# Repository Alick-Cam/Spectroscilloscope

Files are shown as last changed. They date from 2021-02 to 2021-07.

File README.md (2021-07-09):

# FYP-Repo
Software for Final Year Project 2020

Design and develop the necessary hardware and software systems needed to implement an
Oscilloscope and a Spectrum Analyser on a tablet/smartphone running the Android operating
system. To safeguard the handheld device it should communication via the Bluetooth with an
interfacing device that connects to the device under test.
Specifications (oscilloscope and spectrum analyser):
- Frequency: 0Hz – 20kHz.
- Voltage (AC and DC): 0V - 250V
- The device should be designed to use standard oscilloscope probes

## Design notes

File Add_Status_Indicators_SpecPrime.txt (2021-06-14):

<?xml version="1.0" encoding="utf-8"?>
<androidx.constraintlayout.widget.ConstraintLayout xmlns:android="http://schemas.android.com/apk/res/android"
    xmlns:app="http://schemas.android.com/apk/res-auto"
    xmlns:tools="http://schemas.android.com/tools"
    android:layout_width="match_parent"
    android:layout_height="match_parent"
    android:layout_gravity="bottom"
    tools:context=".MainActivity">

    <com.github.mikephil.charting.charts.LineChart
        android:id="@+id/line_chart"
        android:layout_width="match_parent"
        android:layout_height="496sp"
        app:layout_constraintBottom_toBottomOf="parent"
        app:layout_constraintEnd_toEndOf="parent"
        app:layout_constraintStart_toStartOf="parent"
        app:layout_constraintTop_toBottomOf="@+id/beginButton"
        app:layout_constraintVertical_bias = "1.0"
        />

    <Button
        android:id="@+id/connectButton"
        android:layout_width="wrap_content"
        android:layout_height="wrap_content"
        android:layout_marginTop="24dp"
        android:onClick="onClickConnect"
        android:text="@string/connect"
        app:layout_constraintEnd_toStartOf="@+id/probeS"
        app:layout_constraintHorizontal_bias="0.5"
        app:layout_constraintStart_toStartOf="parent"
        app:layout_constraintTop_toTopOf="parent" />

    <Button
        android:id="@+id/stopButton"
        android:layout_width="wrap_content"
        android:layout_height="wrap_content"
        android:onClick="onClickStop"
        android:text="@string/disconnect"
        app:layout_constraintBottom_toBottomOf="@+id/beginButton"
        app:layout_constraintEnd_toStartOf="@+id/button"
        app:layout_constraintHorizontal_bias="0.5"
        app:layout_constraintStart_toEndOf="@+id/beginButton"
        app:layout_constraintTop_toTopOf="@+id/beginButton"
        app:layout_constraintVertical_bias="1.0" />

    <Switch
        android:id="@+id/freqS"
        android:layout_width="wrap_content"
        android:layout_height="wrap_content"
        android:text="@string/FreqS"
        app:layout_constraintBottom_toBottomOf="@+id/probeS"
        app:layout_constraintEnd_toStartOf="@+id/beginButton"
        app:layout_constraintHorizontal_bias="0.5"
        app:layout_constraintStart_toEndOf="@+id/probeS"
        app:layout_constraintTop_toTopOf="@+id/probeS"
        app:layout_constraintVertical_bias="0.0" />

    <Button
        android:id="@+id/button"
        android:layout_width="wrap_content"
        android:layout_height="wrap_content"
        android:onClick="onClickSpectrumAnalysis"
        android:text="@string/spectrum"
        app:layout_constraintBottom_toBottomOf="@+id/stopButton"
        app:layout_constraintEnd_toEndOf="parent"
        app:layout_constraintHorizontal_bias="0.5"
        app:layout_constraintStart_toEndOf="@+id/stopButton"
        app:layout_constraintTop_toTopOf="@+id/stopButton"
        app:layout_constraintVertical_bias="1.0" />

    <Switch
        android:id="@+id/probeS"
        android:layout_width="wrap_content"
        android:layout_height="wrap_content"
        android:text="@string/probeS"
        app:layout_constraintBottom_toBottomOf="@+id/connectButton"
        app:layout_constraintEnd_toStartOf="@+id/freqS"
        app:layout_constraintHorizontal_bias="0.5"
        app:layout_constraintStart_toEndOf="@+id/connectButton"
        app:layout_constraintTop_toTopOf="@+id/connectButton"
        app:layout_constraintVertical_bias="0.666" />

    <Button
        android:id="@+id/beginButton"
        android:layout_width="wrap_content"
        android:layout_height="wrap_content"
        android:onClick="onClickStartTransmission"
        android:text="@string/capture"
        app:layout_constraintBottom_toBottomOf="@+id/freqS"
        app:layout_constraintEnd_toStartOf="@+id/stopButton"
        app:layout_constraintHorizontal_bias="0.5"
        app:layout_constraintStart_toEndOf="@+id/freqS"
        app:layout_constraintTop_toTopOf="@+id/freqS"
        app:layout_constraintVertical_bias="0.476" />

</androidx.constraintlayout.widget.ConstraintLayout>

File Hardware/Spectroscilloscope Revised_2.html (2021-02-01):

Partlist exported from C:/Users/alick/OneDrive/Final Year Cloud/Electronics Engineering (Local)/ECNG3020/FYP-Repo/Hardware/Spectroscilloscope Revised_2.sch at 2/1/2021 2:40 AM

Part | Value | Device | Package | Description | AVAILABILITY | COMMENT | DESCRIPTION | DIGIKEY-PURCHASE-URL | EU_ROHS_COMPLIANCE | MF | MOUSER-PURCHASE-URL | MP | MPN | NUMBER_OF_POSITIONS | OC_FARNELL | OC_NEWARK | PACKAGE | POPULARITY | PRICE | PURCHASE-URL | SPICEPREFIX
0.23VREF | 100k | TRIM_EU-B25P | B25P | POTENTIOMETER | | | | | | | | | | | | | | 7
2.5VREF | 100k | TRIM_EU-B25P | B25P | POTENTIOMETER | | | | | | | | | | | | | | 7
12VPOWER | | DCJ0303 | DCJ0303 | DC POWER JACK
C1 | 22pF | C-EU050-024X044 | C050-024X044 | CAPACITOR, European symbol | | | | | | | | | | | | | | 33 | | | C
C2 | 0.1uF | C-EU050-024X044 | C050-024X044 | CAPACITOR, European symbol | | | | | | | | | | | | | | 33 | | | C
C3 | 0.1u | C-EU050-024X044 | C050-024X044 | CAPACITOR, European symbol | | | | | | | | | | | | | | 33 | | | C
C4 | 22pF | C-EU050-024X044 | C050-024X044 | CAPACITOR, European symbol | | | | | | | | | | | | | | 33 | | | C
C5 | 180pF | C-EU050-024X044 | C050-024X044 | CAPACITOR, European symbol | | | | | | | | | | | | | | 33 | | | C
C6 | 22pF | C-EU050-024X044 | C050-024X044 | CAPACITOR, European symbol | | | | | | | | | | | | | | 33 | | | C
C7 | 0.1u | C-EU050-024X044 | C050-024X044 | CAPACITOR, European symbol | | | | | | | | | | | | | | 33 | | | C
C8 | 0.1uF | C2,5-3 | C2.5-3 | CAPACITOR | | | | | | | | | | | | | | 38
C9 | 10uF | C2,5-3 | C2.5-3 | CAPACITOR | | | | | | | | | | | | | | 38
C10 | 220uF | C2,5-3 | C2.5-3 | CAPACITOR | | | | | | | | | | | | | | 38
C11 | 0.1uF | C-EU050-024X044 | C050-024X044 | CAPACITOR, European symbol | | | | | | | | | | | | | | 33 | | | C
C12 | 10nF | C-EU050-024X044 | C050-024X044 | CAPACITOR, European symbol | | | | | | | | | | | | | | 33 | | | C
C13 | 0.1u | C-EU050-024X044 | C050-024X044 | CAPACITOR, European symbol | | | | | | | | | | | | | | 33 | | | C
C14 | 0.1u | C-EU050-024X044 | C050-024X044 | CAPACITOR, European symbol | | | | | | | | | | | | | | 33 | | | C
C15 | 0.1u | C-EU050-024X044 | C050-024X044 | CAPACITOR, European symbol | | | | | | | | | | | | | | 33 | | | C
C16 | 0.1u | C-EU050-024X044 | C050-024X044 | CAPACITOR, European symbol | | | | | | | | | | | | | | 33 | | | C
D1 | BAT81 | BAT81 | DO34-7 | DIODE | | | | | | | | | | | | | | 5
D2 | BAT81 | BAT81 | DO34-7 | DIODE | | | | | | | | | | | | | | 5
D3 | BAT81 | BAT81 | DO34-7 | DIODE | | | | | | | | | | | | | | 5
D4 | BAT81 | BAT81 | DO34-7 | DIODE | | | | | | | | | | | | | | 5
D5 | BAT81 | BAT81 | DO34-7 | DIODE | | | | | | | | | | | | | | 5
D6 | BAT81 | BAT81 | DO34-7 | DIODE | | | | | | | | | | | | | | 5
HC05 | WIRELESS-BLUETOOTH-HC-05 | WIRELESS-BLUETOOTH-HC-05 | WIRELESS-BLUETOOTH-HC-05 | Bluetooth Transceiver Module based on HC-05 board
IC1 | 7805TV | 7805TV | TO220V | Positive VOLTAGE REGULATOR | | | | | | | | | | | | | | 57
INPUT | 5-1634503-1 | 5-1634503-1 | TE_5-1634503-1 | CONN BNC JACK STR 50 OHM PCB Check prices | Good | 5-1634503-1 | Rf / Coaxial Connector, Bnc Coaxial, Straight Jack, Solder, 50 Ohm, Brass | | Compliant | TE Connectivity | | 5-1634503-1 | | 1 | | | None | | None | https://pricing.snapeda.com/search/part/5-1634503-1/?ref=eda
PROBESELECT | | SW_DIP-1 | EDG-01 | DIP SWITCH | | | | | | | | | | | | | | 3
Q1 | 16MHz | CRYSTALHC49U-V | HC49U-V | CRYSTAL | | | | | | | | | | | 1666969 | unknown | | 22
R1 | 10k | R-EU_0204/7 | 0204/7 | RESISTOR, European symbol | | | | | | | | | | | | | | 79 | | | R
R2 | 10k | R-EU_0204/7 | 0204/7 | RESISTOR, European symbol | | | | | | | | | | | | | | 79 | | | R
R3 | 909k | R-EU_0204/7 | 0204/7 | RESISTOR, European symbol | | | | | | | | | | | | | | 79 | | | R
R4 | 100k | R-EU_0204/7 | 0204/7 | RESISTOR, European symbol | | | | | | | | | | | | | | 79 | | | R
R5 | 1k | R-EU_0204/7 | 0204/7 | RESISTOR, European symbol | | | | | | | | | | | | | | 79 | | | R
R6 | 1k | R-EU_0204/7 | 0204/7 | RESISTOR, European symbol | | | | | | | | | | | | | | 79 | | | R
R7 | 10k | R-EU_0204/7 | 0204/7 | RESISTOR, European symbol | | | | | | | | | | | | | | 79 | | | R
R8 | 1k | R-EU_0204/7 | 0204/7 | RESISTOR, European symbol | | | | | | | | | | | | | | 79 | | | R
R9 | 2k | R-EU_0204/7 | 0204/7 | RESISTOR, European symbol | | | | | | | | | | | | | | 79 | | | R
R10 | 10k | R-EU_0204/7 | 0204/7 | RESISTOR, European symbol | | | | | | | | | | | | | | 79 | | | R
R11 | 1k | R-EU_0204/7 | 0204/7 | RESISTOR, European symbol | | | | | | | | | | | | | | 79 | | | R
SPST | TERMINAL-BLOCK-3.5MM-2-PIN-LONG-PAD | TERMINAL-BLOCK-3.5MM-2-PIN-LONG-PAD | TERMINAL-BLOCK-2-PIN-3.5MM-LONG-PAD | Terminal Block 3.5mm
U$1 | MCP3004-I/P | MCP3004-I/P | DIP254P762X432-14 | A/D Converters | Unavailable | | 10 Bit Analog to Digital Converter 2, 4 Input 1 SAR 14-PDIP | | | Microchip | | MCP3004-I/P | | | | | DIP-14 Microchip | | None
U1 | ATMEGA328P-PU | ATMEGA328P-PU | DIP254P762X457-28 | 8-bit Microcontroller with In-System Programmable Flash Buy Part | Good | | AVR AVR® ATmega Microcontroller IC 8-Bit 20MHz 32KB (16K x 16) FLASH 28-PDIP | https://snapeda.com/shop?store=DigiKey&id=2895131 | | Microchip | https://snapeda.com/shop?store=Mouser&id=2895131 | ATMEGA328P-PU | | | | | DIP-28 Generic | | None
U2 | MCP6024-I/P | MCP6024-I/P | DIP254P762X533-14 | IC OPAMP 2.5V QUAD R-R Check prices | Warning | | IC OPAMP GP 4 CIRCUIT 14DIP | | | Microchip Technology | | MCP6024-I/P | | | | | None | | None | https://pricing.snapeda.com/search/part/MCP6024-I/P/?ref=eda
U3 | MCP6024-I/P | MCP6024-I/P | DIP254P762X533-14 | IC OPAMP 2.5V QUAD R-R Check prices | Warning | | IC OPAMP GP 4 CIRCUIT 14DIP | | | Microchip Technology | | MCP6024-I/P | | | | | None | | None | https://pricing.snapeda.com/search/part/MCP6024-I/P/?ref=eda
VREF_O1 | 100k | TRIM_EU-B25P | B25P | POTENTIOMETER | | | | | | | | | | | | | | 7
VREF_O2 | 100k | TRIM_EU-B25P | B25P | POTENTIOMETER | | | | | | | | | | | | | | 7

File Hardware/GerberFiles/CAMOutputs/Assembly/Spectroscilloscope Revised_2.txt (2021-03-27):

Partlist exported from E:/Google Drive/Final Year Cloud/Electronics Engineering (Local)/ECNG3020/FYP-Repo/Hardware/Spectroscilloscope Revised_2.sch at 3/20/2021 11:01 PM

Qty Value                               Device                              Package                             Parts                               Description                                                      AVAILABILITY COMMENT     DESCRIPTION                                                                    DIGIKEY-PURCHASE-URL                              EU_ROHS_COMPLIANCE MF                   MOUSER-PURCHASE-URL                              MP            MPN NUMBER_OF_POSITIONS OC_FARNELL OC_NEWARK PACKAGE          POPULARITY PRICE PURCHASE-URL                                                 SPICEPREFIX
1                                       DCJ0303                             DCJ0303                             12VPOWER                            DC POWER JACK                                                                                                                                                                                                                                                                                                                                                                                                                                                                            
4                                       PINHD-1X2                           1X02                                0.23CAL, 2.5CAL, O1CAL, O2CAL       PIN HEADER                                                                                                                                                                                                                                                                                                                                                                                      98                                                                                       
1                                       SW_DIP-1                            EDG-01                              PROBESELECT                         DIP SWITCH                                                                                                                                                                                                                                                                                                                                                                                      3                                                                                        
6   0.1u                                C-EU050-024X044                     C050-024X044                        C3, C7, C13, C14, C15, C16          CAPACITOR, European symbol                                                                                                                                                                                                                                                                                                                                                                      33                                                                            C          
3   0.1uF                               C-EU050-024X044                     C050-024X044                        C2, C8, C11                         CAPACITOR, European symbol                                                                                                                                                                                                                                                                                                                                                                      33                                                                            C          
1   100k                                R-EU_0204/7                         0204/7                              R4                                  RESISTOR, European symbol                                                                                                                                                                                                                                                                                                                                                                       79                                                                            R          
4   100k                                TRIM_EU-B25P                        B25P                                0.23VREF, 2.5VREF, VREF_O1, VREF_O2 POTENTIOMETER                                                                                                                                                                                                                                                                                                                                                                                   7                                                                                        
4   10k                                 R-EU_0204/7                         0204/7                              R1, R2, R7, R10                     RESISTOR, European symbol                                                                                                                                                                                                                                                                                                                                                                       79                                                                            R          
1   10nF                                C-EU050-024X044                     C050-024X044                        C12                                 CAPACITOR, European symbol                                                                                                                                                                                                                                                                                                                                                                      33                                                                            C          
1   10uF                                C-EU050-024X044                     C050-024X044                        C9                                  CAPACITOR, European symbol                                                                                                                                                                                                                                                                                                                                                                      33                                                                            C          
1   16MHz                               CRYSTALHC49U-V                      HC49U-V                             Q1                                  CRYSTAL                                                                                                                                                                                                                                                                                                                                                   1666969    unknown                    22                                                                                       
1   180pF                               C-EU050-024X044                     C050-024X044                        C5                                  CAPACITOR, European symbol                                                                                                                                                                                                                                                                                                                                                                      33                                                                            C          
4   1k                                  R-EU_0204/7                         0204/7                              R5, R6, R8, R11                     RESISTOR, European symbol                                                                                                                                                                                                                                                                                                                                                                       79                                                                            R          
1   220uF                               C-EU050-024X044                     C050-024X044                        C10                                 CAPACITOR, European symbol                                                                                                                                                                                                                                                                                                                                                                      33                                                                            C          
3   22pF                                C-EU050-024X044                     C050-024X044                        C1, C4, C6                          CAPACITOR, European symbol                                                                                                                                                                                                                                                                                                                                                                      33                                                                            C          
1   2k                                  R-EU_0204/7                         0204/7                              R9                                  RESISTOR, European symbol                                                                                                                                                                                                                                                                                                                                                                       79                                                                            R          
1   5-1634503-1                         5-1634503-1                         TE_5-1634503-1                      INPUT                               CONN BNC JACK STR 50 OHM PCB Check prices                        Good         5-1634503-1  Rf / Coaxial Connector, Bnc Coaxial, Straight Jack, Solder, 50 Ohm, Brass                                                       Compliant          TE Connectivity                                                       5-1634503-1       1                                        None                        None  https://pricing.snapeda.com/search/part/5-1634503-1/?ref=eda            
1   7805TV                              7805TV                              TO220V                              IC1                                 Positive VOLTAGE REGULATOR                                                                                                                                                                                                                                                                                                                                                                      57                                                                                       
1   909k                                R-EU_0204/7                         0204/7                              R3                                  RESISTOR, European symbol                                                                                                                                                                                                                                                                                                                                                                       79                                                                            R          
1   ATMEGA328P-PU                       ATMEGA328P-PU                       DIP254P762X457-28                   U1                                  8-bit Microcontroller with In-System Programmable Flash Buy Part Good                      AVR AVR® ATmega Microcontroller IC 8-Bit 20MHz 32KB (16K x 16) FLASH 28-PDIP  https://snapeda.com/shop?store=DigiKey&id=2895131                    Microchip            https://snapeda.com/shop?store=Mouser&id=2895131 ATMEGA328P-PU                                              DIP-28 Generic              None                                                                          
6   BAT81                               BAT81                               DO34-7                              D1, D2, D3, D4, D5, D6              DIODE                                                                                                                                                                                                                                                                                                                                                                                           5                                                                                        
1   MCP3004-I/P                         MCP3004-I/P                         DIP254P762X432-14                   U$1                                 A/D Converters                                                   Unavailable               10 Bit Analog to Digital Converter 2, 4 Input 1 SAR 14-PDIP                                                                                        Microchip                                                             MCP3004-I/P                                                DIP-14 Microchip            None                                                                          
2   MCP6024-I/P                         MCP6024-I/P                         DIP254P762X533-14                   U2, U3                              IC OPAMP 2.5V QUAD R-R Check prices                              Warning                   IC OPAMP GP 4 CIRCUIT 14DIP                                                                                                                        Microchip Technology                                                  MCP6024-I/P                                                None                        None  https://pricing.snapeda.com/search/part/MCP6024-I/P/?ref=eda            
1   TERMINAL-BLOCK-3.5MM-2-PIN-LONG-PAD TERMINAL-BLOCK-3.5MM-2-PIN-LONG-PAD TERMINAL-BLOCK-2-PIN-3.5MM-LONG-PAD SPST                                Terminal Block 3.5mm                                                                                                                                                                                                                                                                                                                                                                                                                                                                     
1   WIRELESS-BLUETOOTH-HC-05            WIRELESS-BLUETOOTH-HC-05            WIRELESS-BLUETOOTH-HC-05            HC05                                Bluetooth Transceiver Module based on HC-05 board

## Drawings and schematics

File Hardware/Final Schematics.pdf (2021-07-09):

6/29/2021 9:15 AM f=0.50 E:\Google Drive\Final Year Cloud\Electronics Engineering (Local)\ECNG3020\FYP-Repo\Hardware\Spectroscilloscope Revised_6.sch (Sheet: 1/1) SpiceOrder 1 SpiceOrder 2 SpiceOrder 1 SpiceOrder 2 | SpiceOrder 1 SpiceOrder 2 SpiceOrder 1 SpiceOrder 2 SpiceOrder 1 SpiceOrder 2 SpiceOrder 1 SpiceOrder 2 | SpiceOrder 1 SpiceOrder 2 SpiceOrder 1 SpiceOrder 2

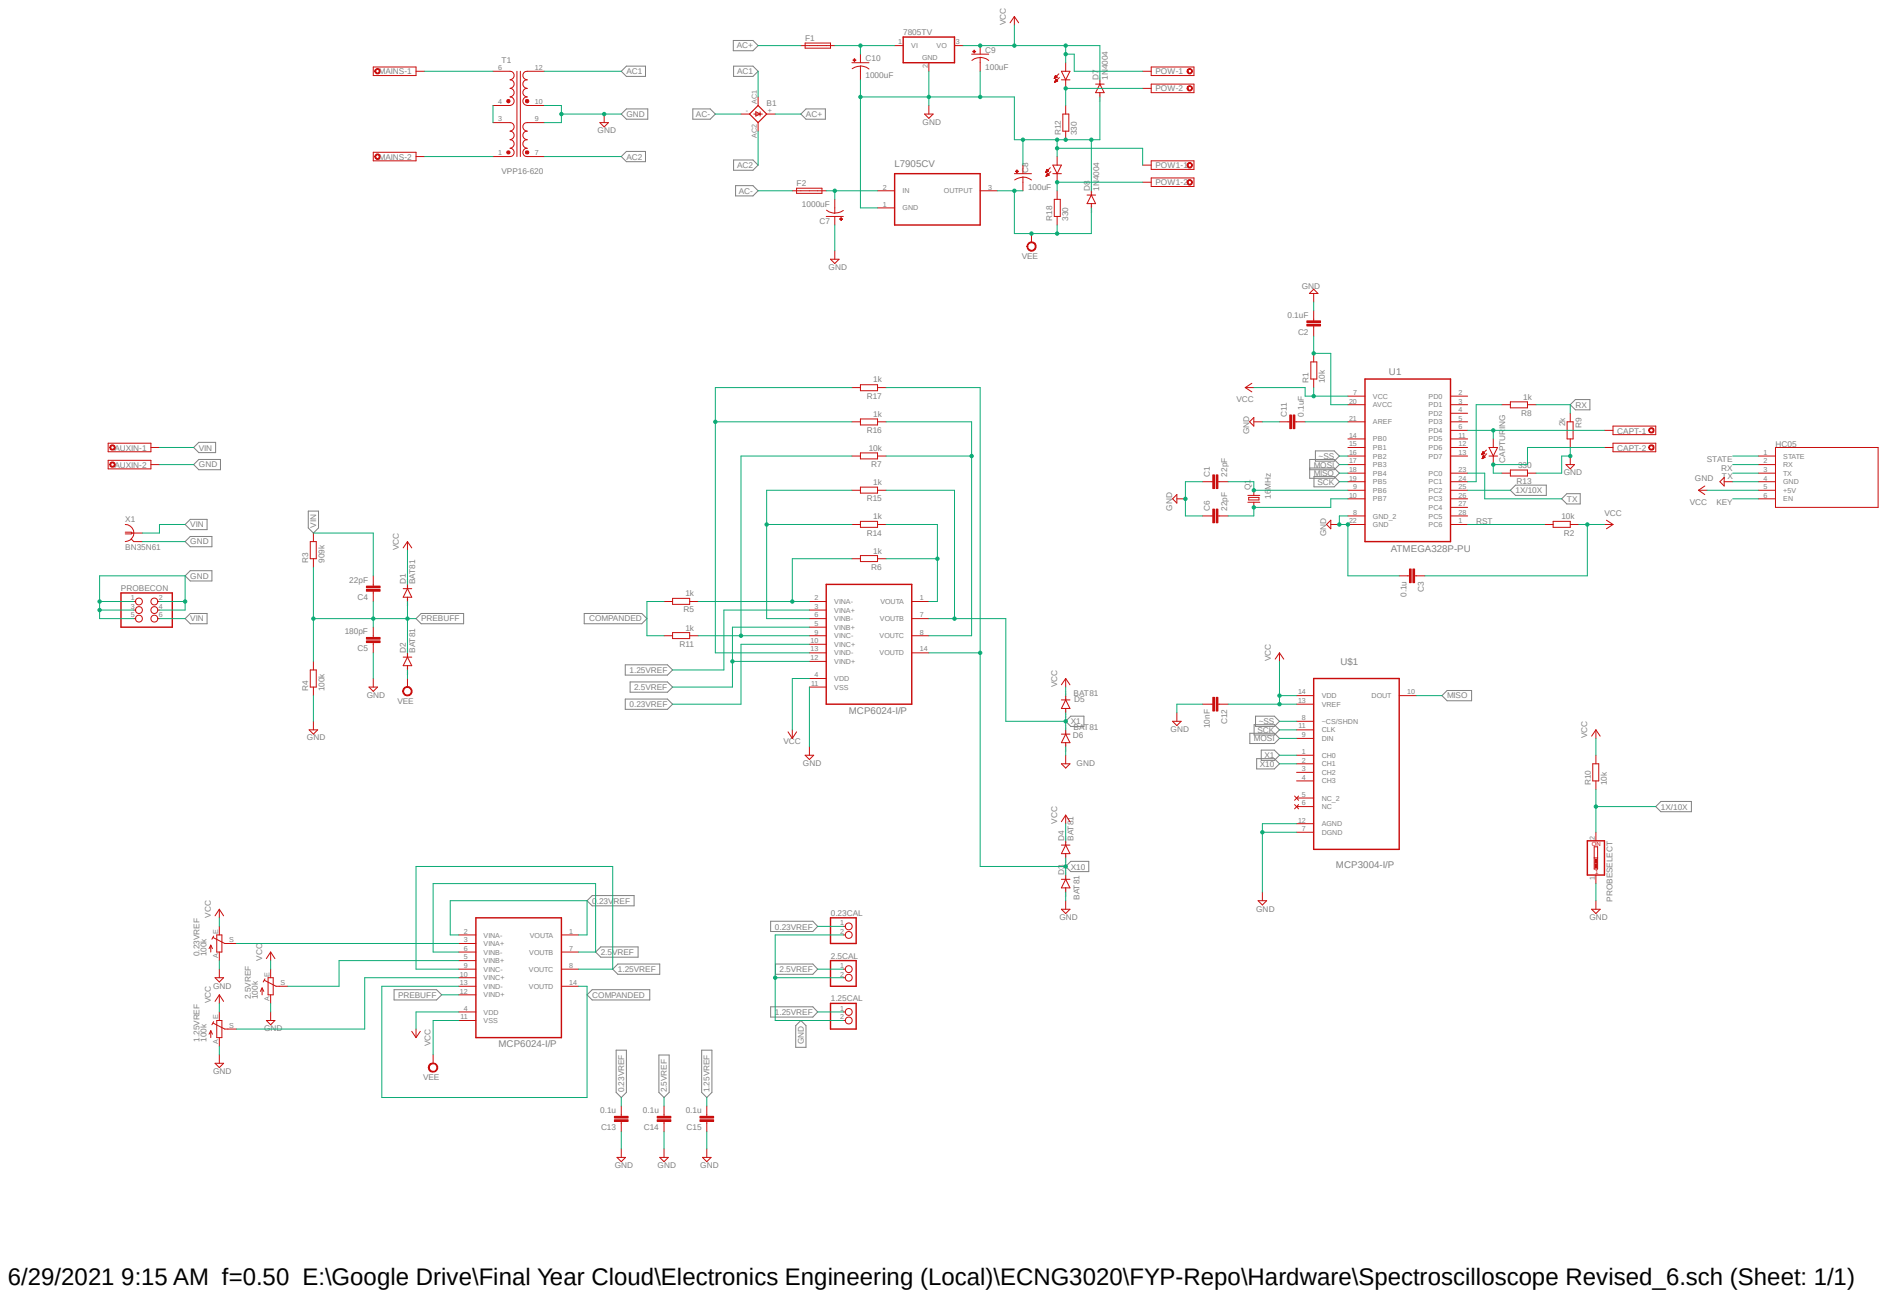
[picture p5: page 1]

AC- | GND 1

PROBECON | GND

GND VCC VCC GND

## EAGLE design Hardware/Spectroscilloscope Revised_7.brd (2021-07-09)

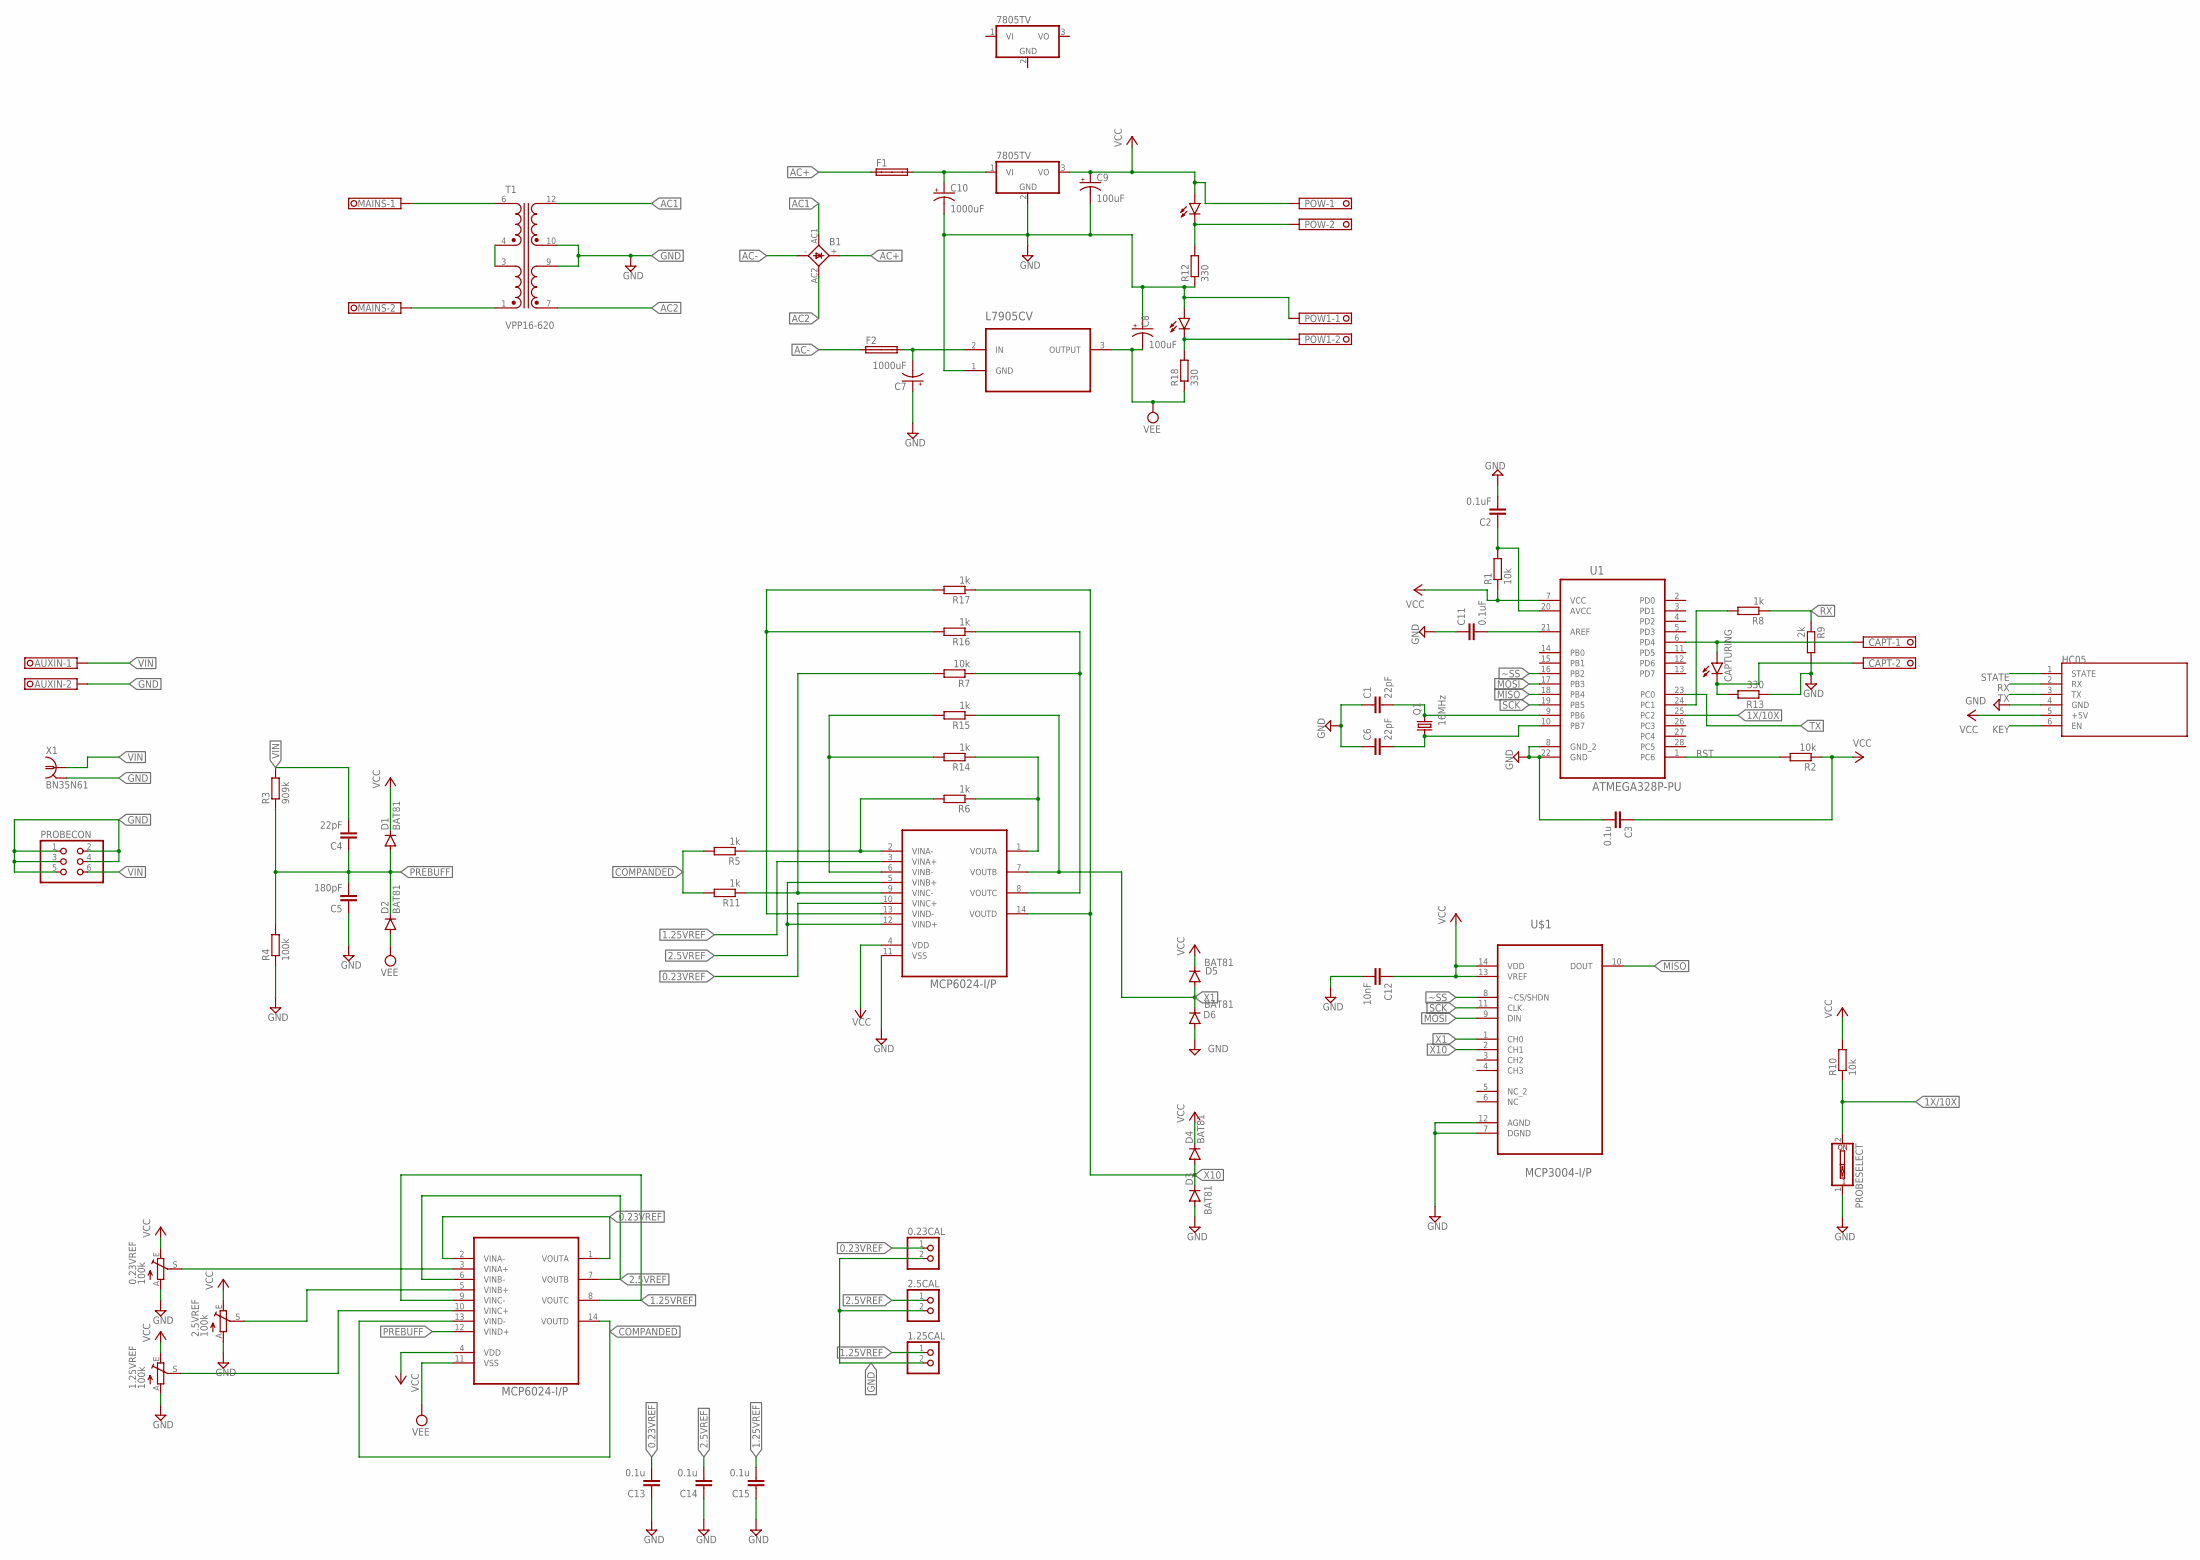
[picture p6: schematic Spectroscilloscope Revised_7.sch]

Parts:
0.23CAL, 1.25CAL, 2.5CAL: PINHD-1X2; 1X02
0.23VREF, 1.25VREF, 2.5VREF: 100k; B25P
AUXIN: TERMINAL-BLOCK-3.5MM-2-PIN-LONG-PAD; TERMINAL-BLOCK-2-PIN-3.5MM-LONG-PAD
B1: 2KBP
C1, C4, C6: 22pF; C050-024X044
C2, C11: 0.1uF; C050-024X044
C3, C13, C14, C15: 0.1u; C050-024X044
C5: 180pF; C050-024X044
C7, C10: 1000uF; E3,5-8
C8, C9: 100uF; E2,5-5
C12: 10nF; C050-024X044
CAPT: TERMINAL-BLOCK-3.5MM-2-PIN-LONG-PAD; TERMINAL-BLOCK-2-PIN-3.5MM-LONG-PAD
CAPTURING: LED5MM
D1, D2, D3, D4, D5, D6: BAT81; DO34-7
F1, F2: SHK20L
HC05: WIRELESS-BLUETOOTH-HC-05
IC1, IC2: 7805TV; TO220V
MAINS: TERMINAL-BLOCK-3.5MM-2-PIN-LONG-PAD; TERMINAL-BLOCK-2-PIN-3.5MM-LONG-PAD
POW, POW1: TERMINAL-BLOCK-3.5MM-2-PIN-LONG-PAD; TERMINAL-BLOCK-2-PIN-3.5MM-LONG-PAD
POWER, POWER1: LED5MM
PROBECON: PINHD-2X3; 2X03
PROBESELECT: SW_DIP-1; EDG-01
Q1: 16MHz; HC49U-V
Q2: L7905CV; TO254P450X1020X1935-3P
R1, R2, R7, R10: 10k; 0204/7
R3: 909k; 0204/7
R4: 100k; 0204/7
R5, R6, R8, R11, R14, R15, R16, R17: 1k; 0204/7
R9: 2k; 0204/7
R12, R13, R18: 330; 0204/7
T1: VPP16-620; XFMR_VPP16-620
U1: ATMEGA328P-PU; DIP254P762X457-28
U2, U3: MCP6024-I/P; DIP254P762X533-14
U$1: MCP3004-I/P; DIP254P762X432-14
X1: BN35N61; B35N61

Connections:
0.23VREF: 0.23CAL.1, C13.2, U2.10 (VINC+), U3.1 (VOUTA), U3.2 (VINA-)
1.25VREF: 1.25CAL.1, C15.2, U2.3 (VINA+), U3.8 (VOUTC), U3.9 (VINC-)
1X/10X: PROBESELECT.2, R10.1, U1.25 (PC2)
2.5VREF: 2.5CAL.1, C14.2, U2.5 (VINB+), U2.12 (VIND+), U3.6 (VINB-), U3.7 (VOUTB)
AC1: B1.AC1, T1.12
AC2: B1.AC2, T1.7
AC+: B1.+, F1.1A
AC-: B1.-, F2.1A
CAPTURING: CAPT.1, CAPTURING.A, U1.6 (PD4)
COMPANDED: R5.2, R11.2, U3.13 (VIND-), U3.14 (VOUTD)
GND: 0.23CAL.2, 0.23VREF.A, 1.25CAL.2, 1.25VREF.A, 2.5CAL.2, 2.5VREF.A, AUXIN.2, C1.1, C2.2, C3.2, C5.1, C6.1, C7.+, C8.+, C9.-, C10.-, C11.1, C12.2, C13.1, C14.1, C15.1, D3.A, D6.A, HC05.4 (GND), IC1.2 (GND), POW1.1, POWER1.A, PROBECON.1, PROBECON.2, PROBECON.3, PROBECON.4, PROBECON.5, PROBESELECT.1, Q2.1 (GND), R4.1, R9.2, R12.1, R13.1, T1.9, T1.10, U1.8 (GND_2), U1.22 (GND), U2.11 (VSS), U$1.7 (DGND), U$1.12 (AGND), X1.2, X1.3 (2), X1.4 (2), X1.5 (2)
KEY: HC05.6 (EN)
MAINS1: MAINS.1, T1.6
MAINS2: MAINS.2, T1.1
MISO: U1.18 (PB4), U$1.10 (DOUT)
MOSI: U1.17 (PB3), U$1.9 (DIN)
unnamed: C1.2, Q1.2, U1.9 (PB6)
unnamed: C6.2, Q1.1, U1.10 (PB7)
unnamed: 2.5VREF.S, U3.5 (VINB+)
unnamed: R6.1, R14.1, U2.1 (VOUTA)
unnamed: R5.1, R6.2, U2.2 (VINA-)
unnamed: C11.2, U1.21 (AREF)
unnamed: 1.25VREF.S, U3.10 (VINC+)
unnamed: C2.1, R1.2, U1.20 (AVCC)
unnamed: 0.23VREF.S, U3.3 (VINA+)
unnamed: T1.3, T1.4
unnamed: POW.2, POWER.K (C), R12.2
unnamed: CAPT.2, CAPTURING.K (C), R13.2
unnamed: R14.2, R15.2, U2.6 (VINB-)
unnamed: R7.2, R11.1, U2.9 (VINC-)
unnamed: R8.2, U1.24 (PC1)
unnamed: POW1.2, POWER1.K (C), R18.2
unnamed: R16.2, R17.2, U2.13 (VIND-)
unnamed: R7.1, R16.1, U2.8 (VOUTC)
NEG: C7.-, F2.2A, Q2.2 (IN)
POS: C10.+, F1.2A, IC1.1 (VI)
PREBUFF: C4.1, C5.2, D1.A, D2.C, R3.1, R4.2, U3.12 (VIND+)
RST: R2.2, U1.1 (PC6)
RX: HC05.2 (RX), R8.1, R9.1
SCK: U1.19 (PB5), U$1.11 (CLK)
STATE: HC05.1 (STATE)
TX: HC05.3 (TX), U1.23 (PC0)
VCC: 0.23VREF.E, 1.25VREF.E, 2.5VREF.E, C3.1, C9.+, C12.1, D1.C, D4.C, D5.C, HC05.5 (+5V), IC1.3 (VO), POW.1, POWER.A, R1.1, R2.1, R10.2, U1.7 (VCC), U2.4 (VDD), U3.4 (VDD), U$1.13 (VREF), U$1.14 (VDD)
VEE: C8.-, D2.A, Q2.3 (OUTPUT), R18.1, U3.11 (VSS)
VIN: AUXIN.1, C4.2, PROBECON.6, R3.2, X1.1
X1: D5.A, D6.C, R15.1, U2.7 (VOUTB), U$1.1 (CH0)
X10: D3.C, D4.A, R17.1, U2.14 (VOUTD), U$1.2 (CH1)
~SS: U1.16 (PB2), U$1.8 (~CS/SHDN)

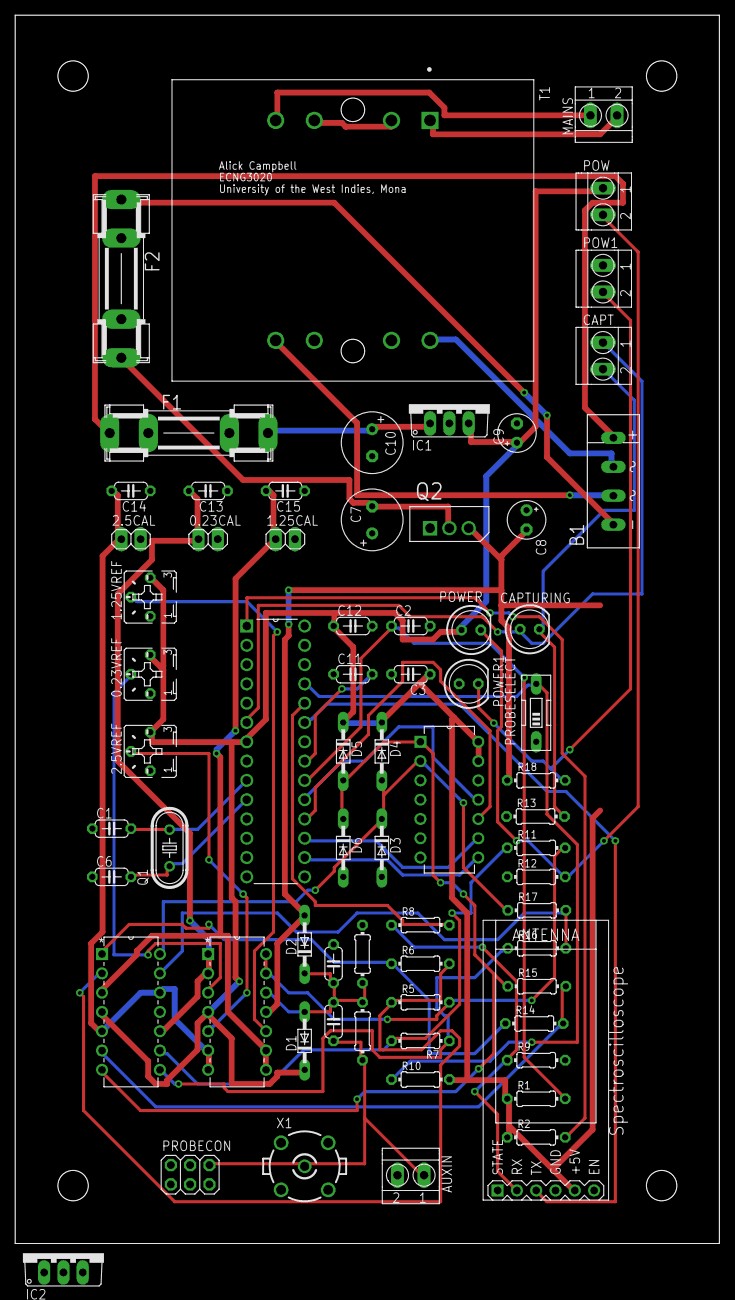
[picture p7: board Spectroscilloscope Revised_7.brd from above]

Board: 2 copper layers, 92.7 x 161.7 mm, 69 parts (0 on the bottom side), 46 nets.

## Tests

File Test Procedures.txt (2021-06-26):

Requirement
Frequency - <=20000Hz
Test 
Using a constant ampitude test the following:
0 Hz 
1kHz
2kHz
3kHz
...
20kHz

AC Amplitude - <= 250V
Using constant frequency test the following:
0V
5V
10V
...
250V

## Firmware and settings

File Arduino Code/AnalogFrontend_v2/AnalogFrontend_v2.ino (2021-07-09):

#include <SPI.h>
#include <SoftwareSerial.h>
SoftwareSerial Spectros(14, 15); // RX | TX
#define SPI_CLOCK 4000000 // 4MHz(3.6MHz) required by the MCP3004
#define chipSelectPin 10
#define nPoints 256
#define X1CHANNEL 0
#define X10CHANNEL 1
int samples1[nPoints];
int samples10[nPoints];
unsigned char data[2*nPoints];
unsigned char channelD[2];
unsigned char samplerate[2];
void setup() {
  // put your setup code here, to run once:
  SPI_setup();
  Serial.begin(115200);
  Spectros.begin(115200); 
}

void loop() {
  /*
  Wait for cature signal from Android device (t => HF, q => LF
  Sample from x1 channel 
  Send Channel 
  Send data
  */
   if (Spectros.available()) {
   char sCommand = Spectros.read();
   Serial.println(sCommand);
   if (sCommand == 't') {
    // use HF
    unsigned long starttime = millis();
    for (int i = 0; i < nPoints ; i ++) {
      samples1[i] = readADC(X1CHANNEL);
//      delayMicroseconds(10); // 200kSPS
    }
    unsigned long timeelapsed = millis()-starttime;
    int sampleRate = (int)(1/((timeelapsed/1000.0)/256.0));
    samplerate[0] = sampleRate >>8;
    samplerate[1]  = sampleRate & 0b0000000011111111;
    int channel = X1CHANNEL;
    toUnsignedChar(channel);
    channelD[0] = channel >>8;
    channelD[1] = channel & 0b0000000011111111;
    // send sample rate
    Spectros.write(samplerate[0]);
    Spectros.write(samplerate[1]);      
    // send channel
    Spectros.write(channelD[0]);
    Spectros.write(channelD[1]);
    for (int i = 0; i < 2*nPoints; i++) {
      Spectros.write(data[i]);
    }
      
   }else if (sCommand == 'q') {
    // Use LF
    unsigned long starttime = millis();
    for (int i = 0; i < nPoints ; i ++) {
      samples1[i] = readADC(X1CHANNEL);
      delay(4); // 256SPS
    }
    unsigned long timeelapsed = millis()-starttime;
    int sampleRate = (int)(1/((timeelapsed/1000.0)/256.0));
    samplerate[0] = sampleRate >>8;
    samplerate[1]  = sampleRate & 0b0000000011111111;
    int channel = X1CHANNEL;
    toUnsignedChar(channel);
    channelD[0] = channel >>8;
    channelD[1] = channel & 0b0000000011111111;
    // send sample rate
    Spectros.write(samplerate[0]);
    Spectros.write(samplerate[1]); 
    // send channel
    Spectros.write(channelD[0]);
    Spectros.write(channelD[1]);
    for (int i = 0; i < 2*nPoints; i++) {
      Spectros.write(data[i]);
    }    
   }
  }

}

// function to convert samples from ADC into an array of 8 bit chars. Every 2 byte represents a single value obtained from the ADC
void toUnsignedChar(int channel) {
  for (int i = 0; i < nPoints; i++) {
    if(channel == X10CHANNEL) {
    data[2*i] = samples10[i] >> 8;
    data[2*i+1] = samples10[i] & 0b0000000011111111;
    }
    else {
    data[2*i] = samples1[i] >> 8;
    data[2*i+1] = samples1[i] & 0b0000000011111111;      
    }
  }
}

// function to setup SPI for communication with MCP3004
void SPI_setup() {
  SPI.begin();
  SPI.beginTransaction(SPISettings(SPI_CLOCK, MSBFIRST, SPI_MODE0));
  pinMode(chipSelectPin, OUTPUT);
  digitalWrite(chipSelectPin, HIGH);  //Immediately set CS (slave select) high so the ADC isn't selected on startup.
}

int readADC(byte channel){
  byte startBit = 0b00000001;
  byte controlByte = 0b10000000 | (channel << 4); // First bit 1 gives us single-ended mode on ADC; the next three bits represent the ADC's analog input
  byte flushByte = 0b00000000; // Flush the ADC to get the remaining byte output.
  
  digitalWrite(chipSelectPin, LOW); //Initiate SPI protocol by dropping slave select low.
  SPI.transfer(startBit); // Fire off our start bit.
  byte readingH = SPI.transfer(controlByte);  // Push in our control byte which tells the ADC what mode to use and what channel we want.
  byte readingL = SPI.transfer(flushByte);  // Get the rest of our output from the ADC by flushing it with a byte of 0s.
  digitalWrite(chipSelectPin, HIGH);  // After flushing, immediately deselect the chip so that it doesn't continue.

  int reading = ((readingH & 0b00000011) << 8) + (readingL); // Per datasheet, we know that only the last two bits of our first transfer contain useful info. The second byte is all useful.

  return reading;
}

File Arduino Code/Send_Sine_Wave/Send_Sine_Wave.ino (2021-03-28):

/*
Code writed to send hardcoded data to android device for testing
*/
#include <SoftwareSerial.h>
SoftwareSerial BTSerial(14, 15); // RX | TX
#define nPoints 512
#define rawnPoints 1024
unsigned char data[2 * nPoints] = {0,0,3,255,3,255,0,0,0,0,3,255,3,255,0,0,0,0,3,255,3,255,0,0,0,0,3,255,3,255,0,0,
                                   0,0,3,255,3,255,0,0,0,0,3,255,3,255,0,0,0,0,3,255,3,255,0,0,0,0,3,255,3,255,0,0,
                                   0,0,3,255,3,255,0,0,0,0,3,255,3,255,0,0,0,0,3,255,3,255,0,0,0,0,3,255,3,255,0,0,
                                   0,0,3,255,3,255,0,0,0,0,3,255,3,255,0,0,0,0,3,255,3,255,0,0,0,0,3,255,3,255,0,0,
                                   0,0,3,255,3,255,0,0,0,0,3,255,3,255,0,0,0,0,3,255,3,255,0,0,0,0,3,255,3,255,0,0,
                                   0,0,3,255,3,255,0,0,0,0,3,255,3,255,0,0,0,0,3,255,3,255,0,0,0,0,3,255,3,255,0,0,
                                   0,0,3,255,3,255,0,0,0,0,3,255,3,255,0,0,0,0,3,255,3,255,0,0,0,0,3,255,3,255,0,0,
                                   0,0,3,255,3,255,0,0,0,0,3,255,3,255,0,0,0,0,3,255,3,255,0,0,0,0,3,255,3,255,0,0,
                                   0,0,3,255,3,255,0,0,0,0,3,255,3,255,0,0,0,0,3,255,3,255,0,0,0,0,3,255,3,255,0,0,
                                   0,0,3,255,3,255,0,0,0,0,3,255,3,255,0,0,0,0,3,255,3,255,0,0,0,0,3,255,3,255,0,0,
                                   0,0,3,255,3,255,0,0,0,0,3,255,3,255,0,0,0,0,3,255,3,255,0,0,0,0,3,255,3,255,0,0,
                                   0,0,3,255,3,255,0,0,0,0,3,255,3,255,0,0,0,0,3,255,3,255,0,0,0,0,3,255,3,255,0,0,
                                   0,0,3,255,3,255,0,0,0,0,3,255,3,255,0,0,0,0,3,255,3,255,0,0,0,0,3,255,3,255,0,0,
                                   0,0,3,255,3,255,0,0,0,0,3,255,3,255,0,0,0,0,3,255,3,255,0,0,0,0,3,255,3,255,0,0,
                                   0,0,3,255,3,255,0,0,0,0,3,255,3,255,0,0,0,0,3,255,3,255,0,0,0,0,3,255,3,255,0,0,
                                   0,0,3,255,3,255,0,0,0,0,3,255,3,255,0,0,0,0,3,255,3,255,0,0,0,0,3,255,3,255,0,0,
                                   0,0,3,255,3,255,0,0,0,0,3,255,3,255,0,0,0,0,3,255,3,255,0,0,0,0,3,255,3,255,0,0,
                                   0,0,3,255,3,255,0,0,0,0,3,255,3,255,0,0,0,0,3,255,3,255,0,0,0,0,3,255,3,255,0,0,
                                   0,0,3,255,3,255,0,0,0,0,3,255,3,255,0,0,0,0,3,255,3,255,0,0,0,0,3,255,3,255,0,0,
                                   0,0,3,255,3,255,0,0,0,0,3,255,3,255,0,0,0,0,3,255,3,255,0,0,0,0,3,255,3,255,0,0,
                                   0,0,3,255,3,255,0,0,0,0,3,255,3,255,0,0,0,0,3,255,3,255,0,0,0,0,3,255,3,255,0,0,
                                   0,0,3,255,3,255,0,0,0,0,3,255,3,255,0,0,0,0,3,255,3,255,0,0,0,0,3,255,3,255,0,0,
                                   0,0,3,255,3,255,0,0,0,0,3,255,3,255,0,0,0,0,3,255,3,255,0,0,0,0,3,255,3,255,0,0,
                                   0,0,3,255,3,255,0,0,0,0,3,255,3,255,0,0,0,0,3,255,3,255,0,0,0,0,3,255,3,255,0,0,
                                   0,0,3,255,3,255,0,0,0,0,3,255,3,255,0,0,0,0,3,255,3,255,0,0,0,0,3,255,3,255,0,0,
                                   0,0,3,255,3,255,0,0,0,0,3,255,3,255,0,0,0,0,3,255,3,255,0,0,0,0,3,255,3,255,0,0,
                                   0,0,3,255,3,255,0,0,0,0,3,255,3,255,0,0,0,0,3,255,3,255,0,0,0,0,3,255,3,255,0,0,
                                   0,0,3,255,3,255,0,0,0,0,3,255,3,255,0,0,0,0,3,255,3,255,0,0,0,0,3,255,3,255,0,0,
                                   0,0,3,255,3,255,0,0,0,0,3,255,3,255,0,0,0,0,3,255,3,255,0,0,0,0,3,255,3,255,0,0,
                                   0,0,3,255,3,255,0,0,0,0,3,255,3,255,0,0,0,0,3,255,3,255,0,0,0,0,3,255,3,255,0,0,
                                   0,0,3,255,3,255,0,0,0,0,3,255,3,255,0,0,0,0,3,255,3,255,0,0,0,0,3,255,3,255,0,0,
                                   0,0,3,255,3,255,0,0,0,0,3,255,3,255,0,0,0,0,3,255,3,255,0,0,0,0,3,255,3,255,0,0};
int samples[nPoints];
void setup()
{
  Serial.begin(9600); 
  BTSerial.begin(115200);  
  sei();
}

void loop()
{
  // Feed any data from bluetooth to Terminal.
  if (BTSerial.available()) {
   if (BTSerial.read() == 't') {
      for(int x = 0; x<rawnPoints; x++) {
      BTSerial.write(data[x]);
      } 
      
   } 
  }

}

































  //Populate array like ABBAABBAAB
//  for(unsigned char x = 0; x<32; x++) {
// 
//  if(x>1)
//  {
//    if((data[x-1] == 255 && data[x-3] == 0)||(data[x-1] == 0 && data[x-2] == 0))
//    {
//      data[x] = 3;
//      data[x+1] = 255;
//      x++;
//    }
//    
//    else if ((data[x-1] == 0 && data[x-2] == 255)||(data[x-1] == 0 && data[x-2] == 255))
//    {
//      data[x] = 0;
//      data[x+1] = 0;
//      x++;     
//    }
//
//  }
//  else
//  {
//      data[x] = 0;
//      data[x+1] = 0;
//      x++;   
//  }
//  Serial.println(data[x]);
//  }

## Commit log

2020-12-22 This commit has the software prior to addition of threads
2021-01-01 SpectroscilloscopeOmega is now graphing random values. Connect Button displays and when connected to spectroscilloscope, the Receive button displays
2021-01-12 MCP3004 Sample Code; Flow Chart for Android App
2021-01-12 Able to receive data within the 0 - 1023 range which is required for the sampled data
2021-01-13 Created New Project in which the fft thread will be tested
2021-01-14 Added Fast Fourier Transform Thread to Spectroscilloscope v1.0
2021-01-21 Now able to receive data over Bluetooth and plot it with a Line Chart TODO - remove bluetooth functionalities from main thread
2021-02-01 Updated Schematics - Added PCB - Generated Parts List - TODO: replace 3.5mm termiinal block with 5mm terminal block
    [Spectroscilloscope Revised.sch, Spectroscilloscope Revised_2.brd, Spectroscilloscope Revised_2.sch]
2021-02-19 Schematics Update - Code Clean up - MCP3004 data Acquisition
    [Spectroscilloscope Revised_2.sch]
2021-03-06 Placed Bluetooth Connection tasks in a seperate Thread
2021-03-27 Wroked on PCB, updated Schematic
    [Spectroscilloscope Revised_2.brd, Spectroscilloscope Revised_2.sch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]
2021-03-28 Max sample size = 512
2021-04-01 Updated Schematics
    [Spectroscilloscope Revised_2.brd, Spectroscilloscope Revised_2.sch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]
2021-04-20 Revised the Front end design - Final revision - multisim simulation works - Testing Breadboard April 21
    [Spectroscilloscope Revised_2.brd, Spectroscilloscope Revised_2.sch, Spectroscilloscope Revised_3.brd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]
2021-05-30 Updated schematics - Further Update needed
    [Spectroscilloscope Revised_4.brd, Spectroscilloscope Revised_4.sch]
2021-06-12 God be with me and this PCB
    [Spectroscilloscope Revised_5.brd, Spectroscilloscope Revised_5.sch, Spectroscilloscope Revised_6.brd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]
2021-06-27 calibrated STEPSIZE and made sample rate dynamic
2021-06-29 Calibrated voltage references to match what is on the embedded system
2021-07-09 Revision to schematics for future upgrade
    [Spectroscilloscope Revised_7.brd, Spectroscilloscope Revised_7.sch]

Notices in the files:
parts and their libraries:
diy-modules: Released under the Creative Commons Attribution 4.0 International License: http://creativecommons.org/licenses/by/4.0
